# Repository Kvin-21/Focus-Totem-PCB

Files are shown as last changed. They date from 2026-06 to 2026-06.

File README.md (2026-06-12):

# Focus Totem

A desk totem that runs a Pomodoro/study timer. Twist the encoder to dial in the minutes, press to start, and the two side LEDs breathe along with the session -
amber while setting up, green while the clock is running, red for the last minute, and then a flash when done. The OLED shows the live countdown and where you are (FOCUS / BREAK / DONE).

It's a 4-input hackpad built around a through-hole Seeed XIAO RP2040 and runs QMK, so it doubles as a tiny macropad.

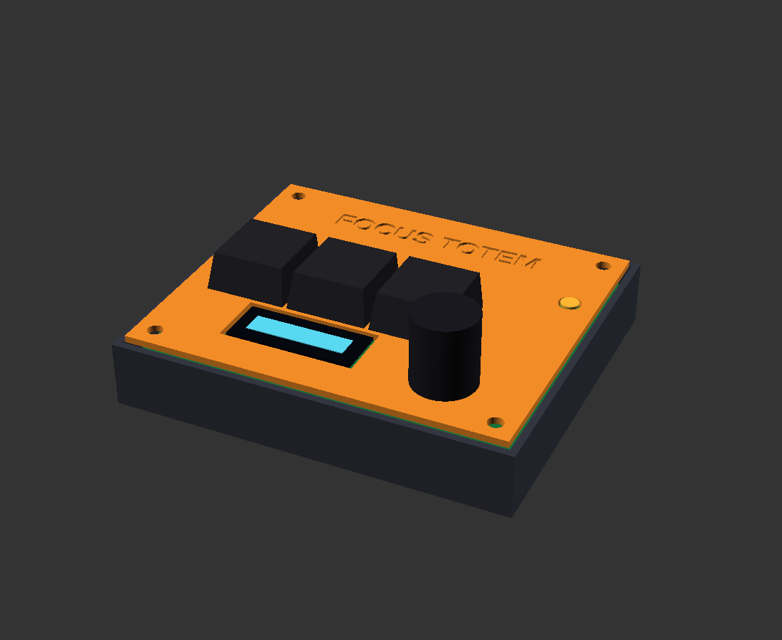
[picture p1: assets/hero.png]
Focus Totem


## Controls

| Input | Does |
|---|---|
| Encoder turn | Set the minutes |
| Encoder press  | Start / pause (same as Key 1) |
| Key 1 | Start / pause |
| Key 2 | Hold to reset to the set time |
| Key 3 | Cycle the short-break preset |

## Schematic

Schematic

## PCB

Two-layer, 84 × 72 mm, ground pour both sides, M3 mounting holes in the corners. The XIAO is through-hole and mounts on the **bottom**, so the macropad is assembled from underneath and its USB port lines up with the slot in the case.

| Top | Bottom |
|-----|---|
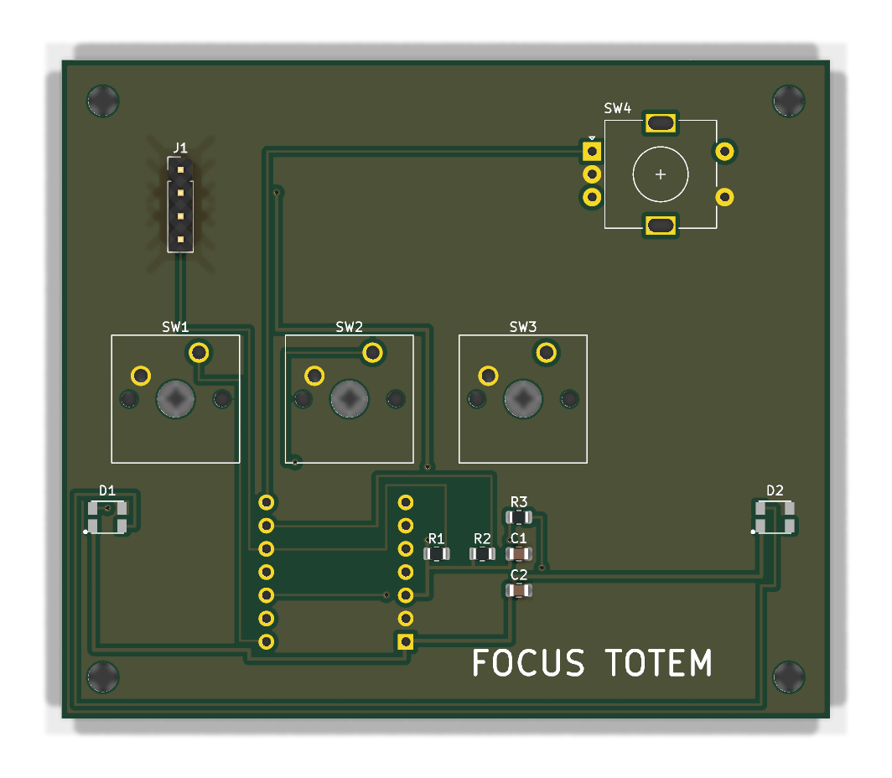
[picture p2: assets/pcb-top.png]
PCB top
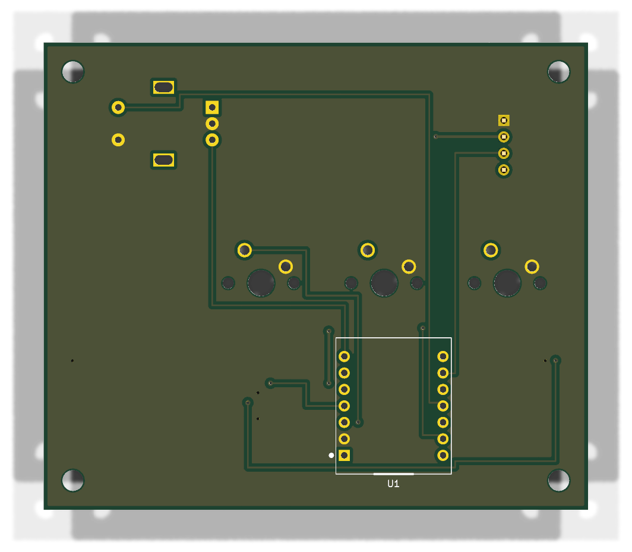
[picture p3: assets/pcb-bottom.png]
PCB bottom
|  |  |

## Case

A 3D-printed sandwich: a switch **plate** on top (the switches clip in, the encoder bush and OLED poke through, the side LEDs show through two little windows), the PCB in the middle, and a **bottom tray** that the XIAO tucks into with a USB slot in the back wall. Four M3 screws drop in from the top, through the plate and PCB, into tapped standoffs in the tray. Every pocket has 0.4 mm of clearance per side, and "FOCUS TOTEM" is engraved into the plate.

Both parts print flat with **no supports** — the plate face-up, the tray floor-down. The USB slot has a 45° self-supporting roof so nothing bridges.

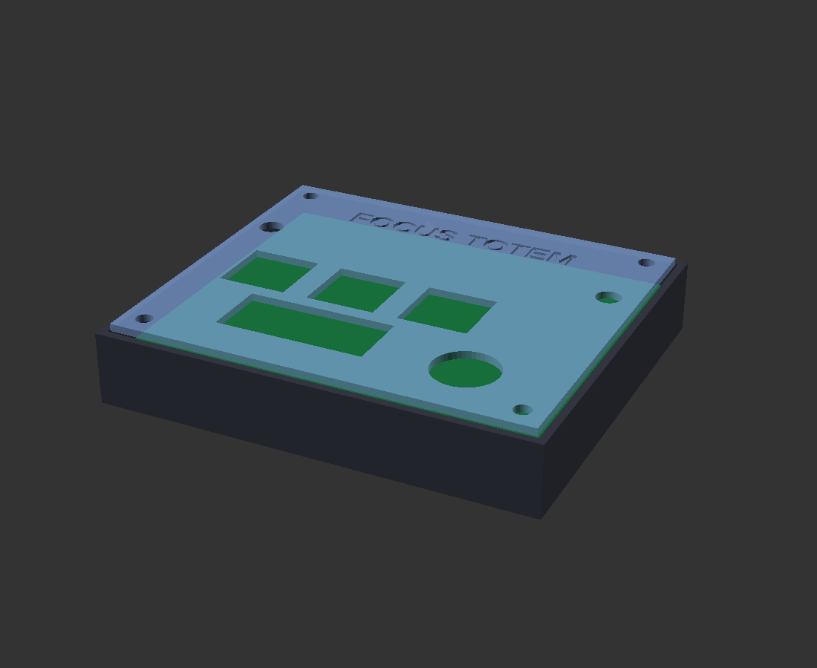
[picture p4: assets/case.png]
Case


## Bill of materials

| Ref | Part | Notes | Qty |
|---|---|---|-----|
| U1 | Seeed XIAO RP2040 (through-hole) | the brains | 1 |
| SW1–SW3  | MX-compatible switch | the three keys | 3 |
| SW4 | Alps EC11 rotary encoder (with switch) | dial + push | 1 |
| J1 | 0.91" SSD1306 OLED, 128×32, I²C | 4-pin module | 1 |
| D1, D2 | SK6812 MINI-E | addressable RGB | 2 |
| R1, R2 | 4.7 kΩ, 0805 | I²C pull-ups | 2 |
| R3 | 470 Ω, 0805 | series on the LED data line  | 1 |
| C1 | 100 nF, 0805 | OLED decoupling | 1 |
| C2 | 10 µF, 0805 | LED bulk | 1 |
| H1–H4 | M3 × 14 screw | sandwich the stack | 4 |

## Wiring / pinout

| Pad  | RP2040 | Goes to |
|---|---|---|
| D0 | GP26 | Key 1 |
| D1 | GP27 | Key 2 |
| D2 | GP28 | Key 3 |
| D3 | GP29 | Encoder switch |
| D4 | GP6 | OLED SDA (I²C1) |
| D5 | GP7 | OLED SCL (I²C1) |
| D6 | GP0 | Encoder A |
| D7 | GP1 | Encoder B |
| D10  | GP3 | SK6812 data in |
| 5V | — | LED V+, C2 |
| 3V3  | — | OLED V+, I²C pull-ups, C1  |
| GND  | — | common ground |

Each key and the encoder switch pull their pin to ground. The encoder common goes to ground. The LEDs are daisy-chained XIAO → R3 → D1 → D2. The OLED answers on I²C address `0x3C`.

## Repository layout

```
CAD/         the assembled model — focus-totem.3mf (whole macropad, one file)
PCB/         KiCad project — schematic, routed board, libraries
Firmware/    QMK keyboard (keyboard.json, config.h, rules.mk, keymaps/)
production/  gerbers.zip, plate + bottom STLs, firmware.uf2, case source (.scad)
assets/      the screenshots above
```

## Firmware — build & flash

The firmware is a QMK keyboard. Drop the `Firmware` folder into a QMK checkout as a keyboard called `focus_totem` and build it:

```sh
# from the root of a qmk_firmware checkout
cp -r Firmware <qmk_firmware>/keyboards/focus_totem
qmk compile -kb focus_totem -km default
```

To flash: plug the XIAO in, double-tap its reset/boot so it mounts as a USB drive, and copy the `.uf2` across. It reboots into the firmware on its own.

## Case — regenerating the model

The case is parametric OpenSCAD ([`production/focus-totem.scad`](production/focus-totem.scad)), driven off the board outline and the KiCad component positions:

```sh
cd production
openscad -D 'part="plate"'    -o focus-totem-plate.stl  focus-totem.scad
openscad -D 'part="bottom"'   -o focus-totem-bottom.stl focus-totem.scad
openscad -D 'part="assembly"' -o ../CAD/focus-totem.3mf focus-totem.scad
```

Print the plate and bottom flat, no supports; PLA or PETG at 0.2 mm is fine.

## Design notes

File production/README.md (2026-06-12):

# Production files

Manufacturing outputs, ready to send off / print / flash.

| File | What it is |
|---|---|
| `gerbers.zip` | Gerbers + drill file for the PCB (KiCad, 2-layer) |
| `focus-totem-plate.stl` | Top switch plate — print flat, face-up, no supports |
| `focus-totem-bottom.stl` | Bottom tray — print flat, floor-down, no supports |
| `firmware.uf2` | Compiled QMK firmware (RP2040) |
| `focus-totem.scad` | OpenSCAD source the two STLs and the CAD model come from |

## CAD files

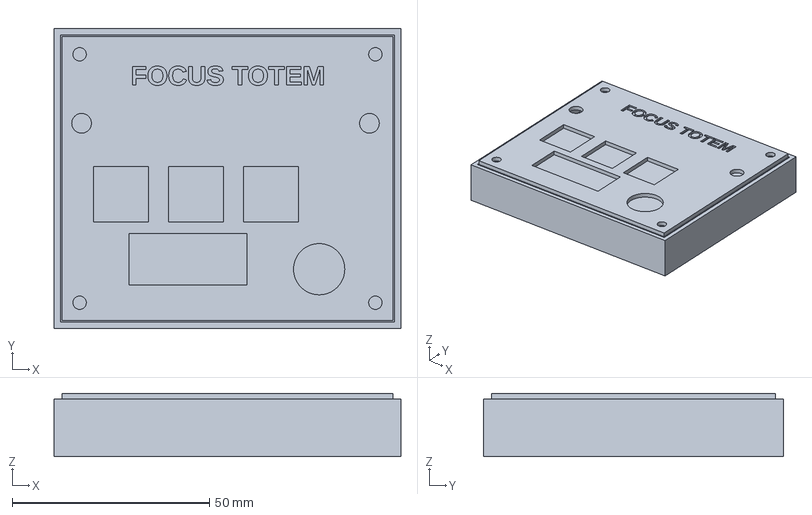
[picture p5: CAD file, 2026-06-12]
CAD/focus-totem.3mf
88.0 x 76.0 x 16.1 mm

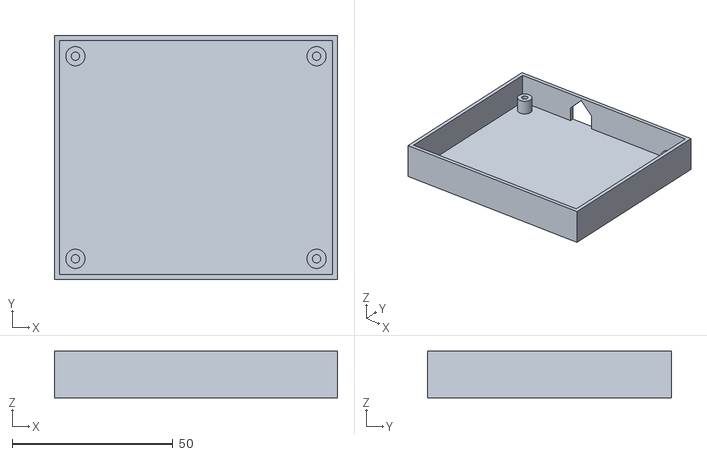
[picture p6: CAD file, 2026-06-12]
production/focus-totem-bottom.stl
88.0 x 76.0 x 14.6

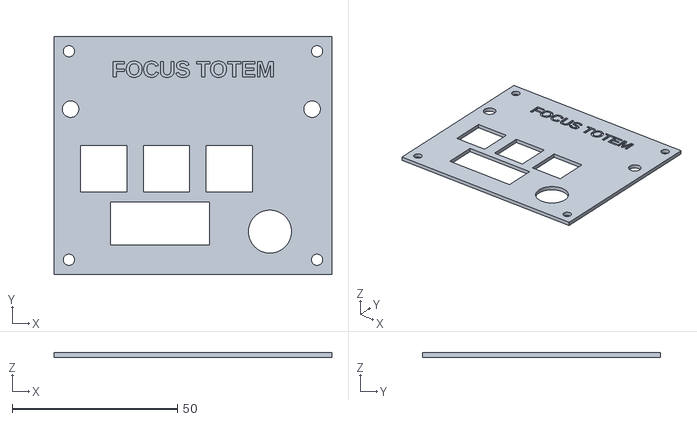
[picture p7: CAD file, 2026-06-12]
production/focus-totem-plate.stl
84.0 x 72.0 x 1.50

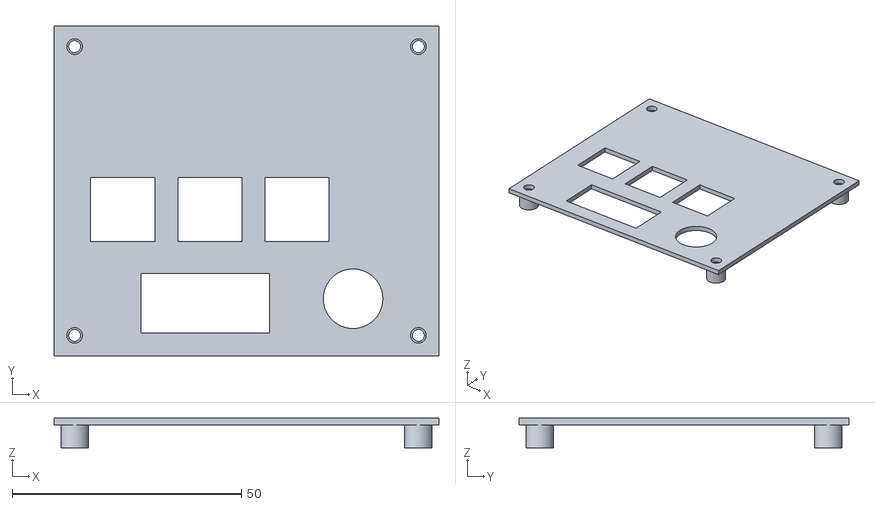
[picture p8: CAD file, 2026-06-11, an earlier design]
case/focus-totem-plate.stl
84.0 x 72.0 x 6.50

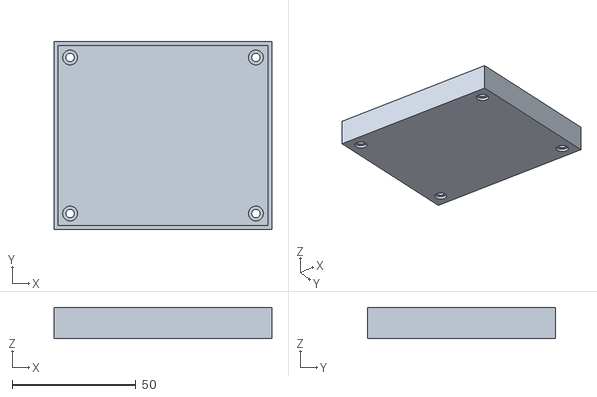
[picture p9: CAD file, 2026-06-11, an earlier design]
case/focus-totem-bottom.stl
88.0 x 76.0 x 12.6

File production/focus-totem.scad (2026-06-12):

// Focus Totem — sandwich case (bottom tray + switch plate)
// Feature coordinates are board-local mm: (0,0) is the top-left corner of the
// PCB, matching the KiCad layout. The XIAO mounts on the underside of the PCB
// and hangs into the tray. Four M3 screws drop in from the top through the
// plate and the PCB into tapped standoffs in the tray.
//
// Both parts print flat, no supports: the plate top-up, the tray floor-down.
//   openscad -D 'part="plate"'    -o focus-totem-plate.stl    focus-totem.scad
//   openscad -D 'part="bottom"'   -o focus-totem-bottom.stl   focus-totem.scad
//   openscad -D 'part="assembly"' -o focus-totem.3mf          focus-totem.scad

part = "plate";          // "plate", "bottom" or "assembly"

board_w   = 84;          // PCB outline
board_h   = 72;
board_t   = 1.6;
tol       = 0.4;         // print tolerance, per side

wall      = 2;
floor_t   = 2;
plate_t   = 1.5;
standoff  = 6;           // floor to PCB underside (clears the bottom XIAO)
gap       = 5;           // PCB top to plate underside (MX body)

post_d    = 6;           // standoff outer diameter
m3_clear  = 3.4;
m3_tap    = 2.6;

sw_cut    = 14;          // MX plate cut-out
enc_d     = 13;          // encoder body + bush clearance
led_d     = 5;           // light window over each side LED
usb_w     = 11;

holes     = [[4.5,4.5],[79.5,4.5],[4.5,67.5],[79.5,67.5]];
switches  = [[15,32],[34,32],[53,32]];
encoder   = [65.25,13];
leds      = [[5,50],[78,50]];
oled_pos  = [17,9];      // OLED display window
oled_size = [30,13];
usb_x     = 30;          // USB sits on the +y edge

shell_h   = floor_t + standoff + board_t + gap;   // walls reach the plate
$fn = 48;

module plate() {
    difference() {
        cube([board_w, board_h, plate_t]);
        for (s = switches)
            translate([s[0] - sw_cut/2, s[1] - sw_cut/2, -1]) cube([sw_cut, sw_cut, plate_t + 2]);
        translate([encoder[0], encoder[1], -1]) cylinder(h = plate_t + 2, d = enc_d);
        translate([oled_pos[0], oled_pos[1], -1]) cube([oled_size[0], oled_size[1], plate_t + 2]);
        for (l = leds) translate([l[0], l[1], -1]) cylinder(h = plate_t + 2, d = led_d);
        for (h = holes) translate([h[0], h[1], -1]) cylinder(h = plate_t + 2, d = m3_clear);
        // engraved branding, sits proud-free on the top face
        translate([board_w/2, 62, plate_t - 0.6])
            linear_extrude(0.7) text("FOCUS TOTEM", size = 5, font = "Liberation Sans:style=Bold",
                                     halign = "center", valign = "center");
    }
}

module usb_cutter() {
    // house-shaped opening: square bottom + sharp 45 deg roof so the top self-supports
    translate([usb_x, board_h + wall + 1, floor_t])
        rotate([90, 0, 0])
            linear_extrude(wall + 2)
                polygon([[-usb_w/2, 0], [usb_w/2, 0], [usb_w/2, standoff],
                         [0, standoff + usb_w/2], [-usb_w/2, standoff]]);
}

module bottom() {
    difference() {
        union() {
            difference() {
                translate([-wall, -wall, 0]) cube([board_w + 2*wall, board_h + 2*wall, shell_h]);
                translate([-tol, -tol, floor_t]) cube([board_w + 2*tol, board_h + 2*tol, shell_h + 1]);
                usb_cutter();
            }
            for (h = holes) translate([h[0], h[1], floor_t]) cylinder(h = standoff, d = post_d);
        }
        // tapped blind holes in the standoffs (screws come down from the top)
        for (h = holes) translate([h[0], h[1], floor_t]) cylinder(h = standoff + 0.1, d = m3_tap);
    }
}

// blank PCB stand-in, for the assembled model
module pcb_blank() {
    translate([0, 0, floor_t + standoff]) cube([board_w, board_h, board_t]);
}

// see_through tints the plate for a nicer hero render; the exported model stays solid
module assembly(see_through = false) {
    color([0.20, 0.21, 0.25]) bottom();            // graphite tray
    color([0.09, 0.44, 0.23]) pcb_blank();         // green PCB
    color(see_through ? [0.50, 0.64, 0.86, 0.72] : [0.95, 0.55, 0.15])
        translate([0, 0, shell_h]) plate();        // frosted top, just a hint see-through
}

// --- render-only fittings (keycaps, knob, screen, LEDs) for the hero shot.
// These are real parts, not printed, so they live only in the "hero" render.
module keycap() {
    hull() {
        translate([-9, -9, 0]) cube([18, 18, 0.1]);
        translate([-8, -7, 8]) cube([16, 16, 0.1]);   // slight front taper
    }
}
module fittings() {
    z0 = shell_h + plate_t;                            // plate top
    color([0.13, 0.13, 0.15]) for (s = switches) translate([s[0], s[1], z0]) keycap();
    color([0.10, 0.10, 0.12]) translate([encoder[0], encoder[1], z0]) cylinder(d = 14, h = 16);
    color([0.02, 0.03, 0.06]) translate([oled_pos[0] + 1, oled_pos[1] + 1, z0 - 0.9])
        cube([oled_size[0] - 2, oled_size[1] - 2, 0.8]);
    color([0.35, 0.85, 0.95]) translate([oled_pos[0] + 4, oled_pos[1] + 4, z0 - 0.4])
        cube([oled_size[0] - 8, oled_size[1] - 8, 0.5]);   // a lit display hint
    color([1.0, 0.72, 0.2]) for (l = leds) translate([l[0], l[1], z0 - 0.3]) cylinder(d = led_d - 1, h = 0.6);
}
module hero() { assembly(false); fittings(); }

if (part == "plate") plate();
else if (part == "assembly") assembly(false);      // solid, for the .3mf
else if (part == "render")   assembly(true);       // tinted case, for the fit shot
else if (part == "hero")     hero();               // finished macropad, for the overall shot
else bottom();

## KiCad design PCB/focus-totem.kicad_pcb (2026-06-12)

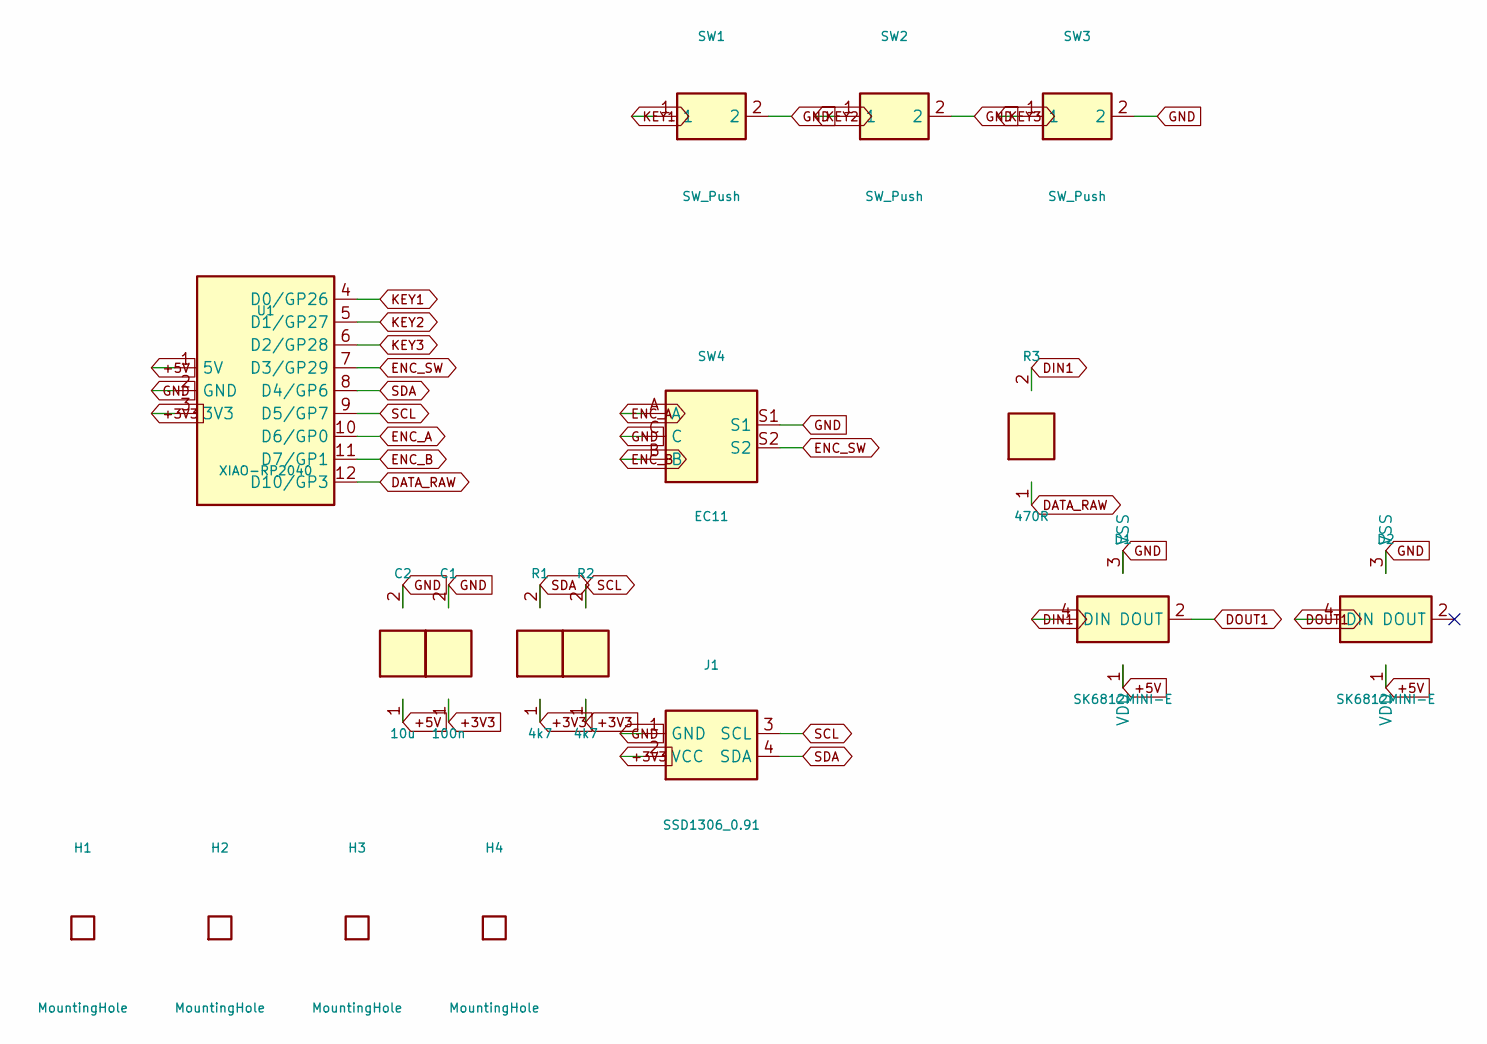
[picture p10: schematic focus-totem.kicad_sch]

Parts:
C1: 100n; C_0805_2012Metric
C2: 10u; C_0805_2012Metric
D1, D2: SK6812MINI-E
H1, H2, H3, H4: MountingHole; MountingHole_3.2mm_M3
J1: SSD1306_0.91; PinHeader_1x04_P2.54mm_Vertical
R1, R2: 4k7; R_0805_2012Metric
R3: 470R; R_0805_2012Metric
SW1, SW2, SW3: SW_Push; SW_Cherry_MX_1.00u_PCB
SW4: EC11; RotaryEncoder_Alps_EC11E-Switch_Vertical_H20mm
U1: XIAO-RP2040

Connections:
+3V3: C1.1, J1.2 (VCC), R1.1, R2.1, U1.3 (3V3)
+5V: C2.1, D1.1 (VDD), D2.1 (VDD), U1.1 (5V)
DATA_RAW: R3.1, U1.12 (D10/GP3)
DIN1: D1.4 (DIN), R3.2
DOUT1: D1.2 (DOUT), D2.4 (DIN)
ENC_A: SW4.A, U1.10 (D6/GP0)
ENC_B: SW4.B, U1.11 (D7/GP1)
ENC_SW: SW4.S2, U1.7 (D3/GP29)
GND: C1.2, C2.2, D1.3 (VSS), D2.3 (VSS), J1.1 (GND), SW1.2, SW2.2, SW3.2, SW4.C, SW4.S1, U1.2 (GND)
KEY1: SW1.1, U1.4 (D0/GP26)
KEY2: SW2.1, U1.5 (D1/GP27)
KEY3: SW3.1, U1.6 (D2/GP28)
SCL: J1.3 (SCL), R2.2, U1.9 (D5/GP7)
SDA: J1.4 (SDA), R1.2, U1.8 (D4/GP6)

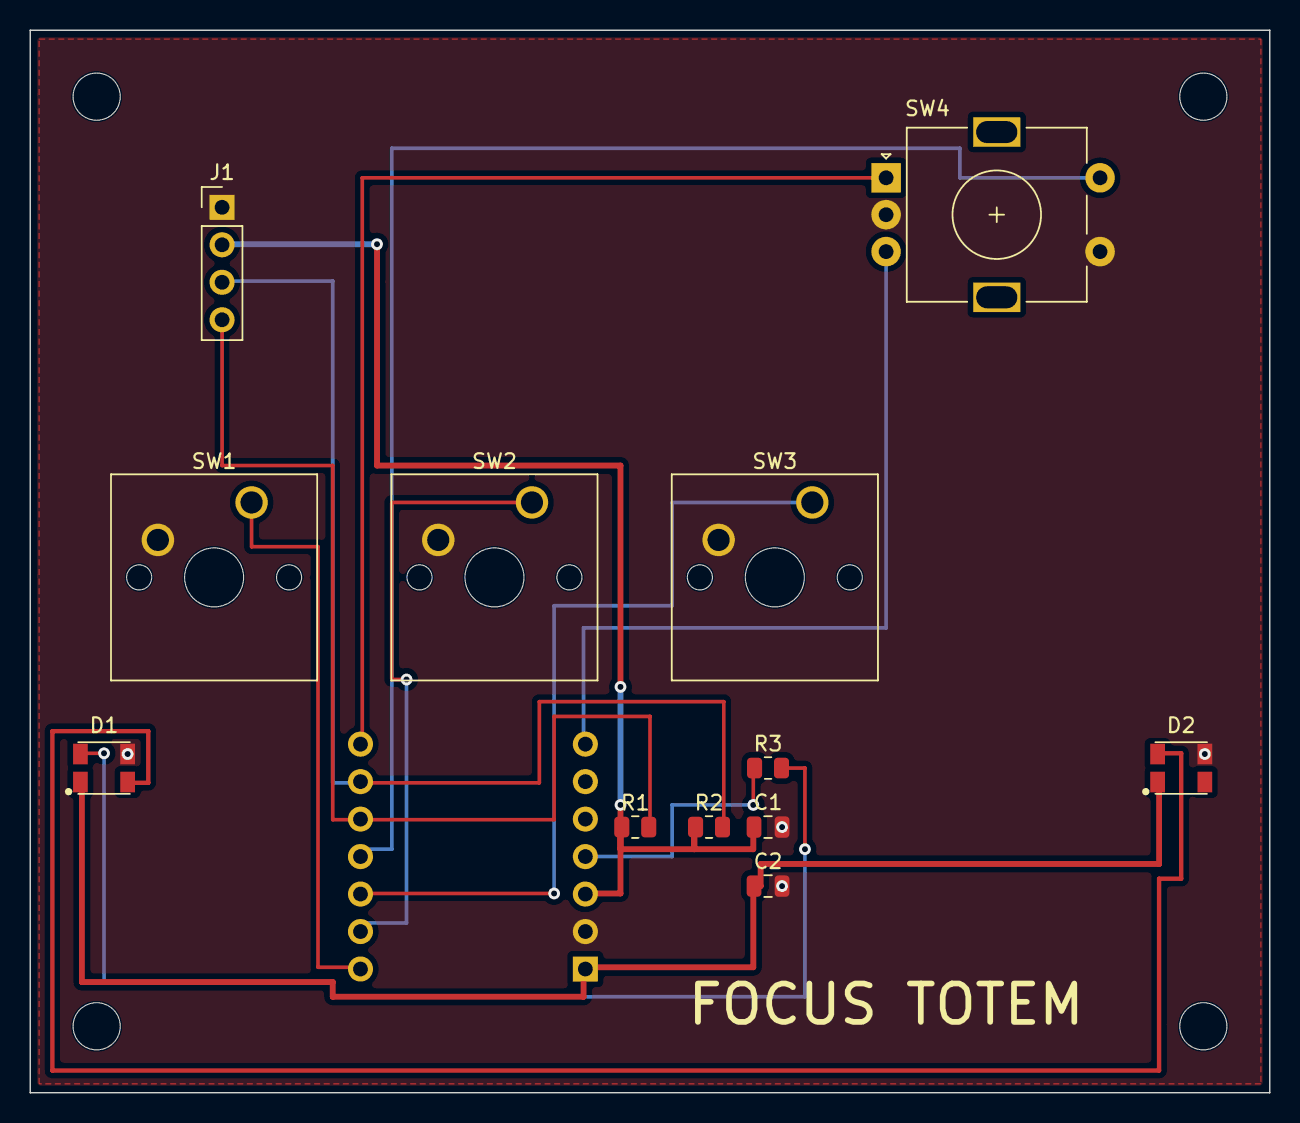
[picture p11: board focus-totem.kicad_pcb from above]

Board: 2 copper layers, 84.0 x 72.0 mm, 17 parts (1 on the bottom side), 14 nets.

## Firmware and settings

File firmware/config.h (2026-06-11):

#pragma once

/* The OLED sits on I2C1 — D4/D5 on the XIAO are GP6/GP7. */
#define I2C_DRIVER I2CD1
#define I2C1_SDA_PIN GP6
#define I2C1_SCL_PIN GP7

#define OLED_DISPLAY_128X32

/* the timer handles its own idle blanking, so leave QMK's auto-off out of it */
#define OLED_TIMEOUT 0

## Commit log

2026-06-10 Added initial PCB and firmware
    [focus-totem.kicad_pcb, focus-totem.kicad_sch]
2026-06-11 Added Pomodoro timer, RGB/OLED, and updates
    [focus-totem.kicad_pcb, focus-totem.kicad_sch]
2026-06-11 Add case files and update README
    Add the case TLs (plate + bottom), and updated Readme
    [focus-totem-bottom.stl, focus-totem-plate.stl, focus-totem.kicad_pcb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]
2026-06-12 Add PCB, CAD and production files
    Added full KiCad board (PCB/focus-totem.kicad_pcb), footprints and symbols, and XIAO/RGB LED footprint + reorganised files
    [focus-totem-assembly.3mf, focus-totem-bottom.stl, focus-totem-plate.stl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]
2026-06-12 Update to files and images
    [focus-totem-assembly.3mf, focus-totem-bottom.stl, focus-totem-plate.stl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]
